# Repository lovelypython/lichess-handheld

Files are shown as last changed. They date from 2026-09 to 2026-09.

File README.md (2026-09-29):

# Lichess Handheld

ESP32-C5 handheld chess terminal project, recovered as a chronological Git history from the Mac/Python simulator through touchscreen testing and the final firmware refinements.

## Development stages

- Python/Mac simulator: board interaction, online flow, clocks, optimistic moves, history navigation, hints, and animation.
- ESP32-C5 PlatformIO port: display, backlight, sleep/wake, Wi-Fi, Lichess client, chess rules, puzzle and online-game screens.
- Touch testing: XPT2046 baseline, standalone diagnostic, independent software SPI, and heartbeat diagnostics.
- Firmware refinement: regional display refresh, TLS setup, landscape rendering, calibrated touch, mirrored-X correction, stale-cell prevention, and puzzle feedback.

## Hardware

Target hardware is a Waveshare ESP32-C5 board with a 480x320 SPI display and XPT2046 touch controller. The current enclosure design is in [hardware/enclosure](hardware/enclosure/).

The enclosure package includes the v05 OpenSCAD source and printable package, plus the v06 rear-shell update. The handoff document records the fit, screw, battery-door, ESP clip, antenna, and Bambu Lab A1 mini printing constraints.

## Build

Install PlatformIO and build the selected historical revision locally:

```bash
pio run -e esp32c5
```

Keep Wi-Fi and Lichess credentials in a local, untracked configuration. This repository contains no passwords, network names, access tokens, compiled firmware images, checksum bundles, or upload wrappers.

## Safety

Do not commit credentials or distribute precompiled firmware. Review the wiring and battery protection before powering the handheld.

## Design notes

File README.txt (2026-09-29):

# Lichess Handheld

This is a recovered historical source snapshot for the ESP32-C5 Lichess handheld project.

## Build from source

Use PlatformIO to build the selected revision locally. No compiled firmware images are distributed in this repository.

```bash
pio run -e esp32c5
```

## Local configuration

Set Wi-Fi and Lichess credentials only in your local configuration. Do not commit passwords, network names, or tokens.

## History

Each commit preserves one recovered development milestone, from the Python simulator through touchscreen diagnostics and the ESP32-C5 firmware.

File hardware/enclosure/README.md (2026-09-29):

# 3D enclosure

Files in this directory:

- `lichess_handheld_enclosure_v05.scad`: parametric source.
- `lichess_handheld_enclosure_v05.zip`: v05 printable package containing the front shell, rear shell, battery cover, ESP clip, and fit-test model.
- `lichess_handheld_enclosure_v06_back.zip`: v06 rear-shell update with the lowered ESP area.
- `GPT6_ESP32C5_Lichess_Enclosure_Handoff.md`: dimensions, fit notes, hardware assumptions, and print guidance.

The v05 design targets the 4-inch 480x320 display, ESP32-C5 board, 18650 battery compartment, rocker switch, antenna clearance, short M2.5 case screws, and Bambu Lab A1 mini FDM printing. STL files remain packaged so the enclosure can be downloaded as one reproducible artifact.

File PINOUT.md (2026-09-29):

# MSP4021 / ST7796S + XPT2046 wiring — v1.0.7

For the first build, only connect the Waveshare ESP32-C5 board and the 4.0" display module.

| LCD pin | Connect to ESP32-C5 | Notes |
|---|---|---|
| VCC | **5V** | Main module power |
| GND | GND | Common ground |
| CS | GPIO23 | LCD chip select |
| RESET | GPIO0 | LCD reset |
| DC/RS | GPIO24 | LOW command / HIGH data |
| SDI (MOSI) | GPIO8 | LCD hardware-SPI MOSI |
| SCK | GPIO10 | LCD hardware-SPI clock |
| **LED** | **GPIO3** | Backlight control; HIGH=on, LOW=off; no 3V3 splitter needed |
| SDO (MISO) | GPIO9 | LCD hardware-SPI MISO |
| T_CLK | **GPIO5** | Touch software-SPI clock |
| T_CS | GPIO1 | Touch chip select |
| T_DIN | **GPIO7** | Touch software-SPI MOSI |
| T_DO | **GPIO25** | Touch software-SPI MISO |
| T_IRQ | GPIO4 | Touch interrupt, active LOW |

SD-card pins are not connected in v1.0.

## Why LED goes to GPIO3

The MSP4021 schematic includes an onboard S8050 transistor and 1 kΩ drive resistor for the backlight.
The module's `LED` header pin is therefore a **logic/PWM control input**, marked as active HIGH by the
manufacturer. It does not need to occupy the ESP32-C5 board's only 3V3 header pin.

This also gives real screen blanking:
- firmware sends ST7796S `DISPOFF` + `SLPIN`;
- GPIO3 goes LOW and the backlight turns off;
- XPT2046 remains powered;
- a touch IRQ wakes the panel and backlight.

## GPIO choices

- GPIO6 and GPIO15 are occupied on the Waveshare board.
- GPIO13/14 are left untouched for native USB/JTAG.
- GPIO27 drives the onboard RGB LED.
- GPIO28 is BOOT.
- GPIO3 is exposed and is used only for LCD backlight control here.
- The ESP32-C5 has one general-purpose hardware SPI controller, so the LCD uses
  hardware SPI and XPT2046 uses an independent software SPI bus on GPIO5/7/25.

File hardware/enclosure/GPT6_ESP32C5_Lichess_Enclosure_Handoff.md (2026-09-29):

# ESP32-C5 Lichess 掌机外壳设计交接文档

> 交给 GPT-6：请**不要沿用之前的外壳结构**，只把下面内容当作硬件尺寸与用户要求，从零重新思考内部布局、固定方式和可打印结构。

## 1. 项目目标

做一个可 3D 打印的手持 Lichess 国际象棋设备外壳。

正面是一块 4.0 英寸 480×320 触摸屏；内部放 Waveshare ESP32-C5 开发板、18650 电池盒和外置棒状 Wi‑Fi 天线；侧面有一个船型电源开关。

用户使用 Bambu Lab A1 mini 打印，优先考虑普通 FDM 可稳定打印和装配，不追求极限薄。

---

## 2. 已确定硬件

### 显示屏

型号/卖家标识：MSP4020 / 4.0 寸 SPI 触摸显示屏

- 尺寸：4.0 inch
- 类型：TFT
- 分辨率：480 × 320
- 驱动 IC：ST7796S
- 显示接口：4-wire SPI
- 触摸：电阻触摸
- 有效显示区域：83.52 × 55.68 mm
- PCB 外形尺寸：108.04 × 61.74 mm
- 屏幕方向：横屏
- 用户希望正面只保留必要边框，不要把有效显示区遮掉
- 屏幕必须有可靠的机械固定，不能只靠壳体夹住后在内部晃动
- 可以使用屏幕 PCB 自带安装孔固定，但正式 CAD 前请重新核对该具体板子的安装孔位置/孔径

### ESP32

开发板：

**Waveshare ESP32-C5-WIFI6-KIT-N32R8-UM**

已知/此前核对的板尺寸：

- PCB/板卡外形约：61.40 × 25.40 mm
- N32R8：32 MB Flash + 8 MB PSRAM
- UM：预焊排针 + 外置天线版本

要求：

- ESP32 必须可靠固定，不能在内部晃动
- 最好利用板上安装孔；如果官方孔位尺寸不能百分百确认，不要猜，改用可靠的压片/夹具/内部小支架
- USB 接口必须从外壳外部可接近，便于烧录、调试和充电
- 不要让固定结构压到 USB、排针、天线连接器或元件

### 外置棒状天线

此前核对的天线本体尺寸约：

- 长度：109 mm
- 直径/最大宽度：约 10 mm

最新要求：

- **天线整个放在外壳内部**
- 不需要让长天线从外壳伸出去
- 必须有现实可装配的路径，不能设计成“封闭管道里凭空出现”
- 最好打开前/后壳后可以直接放入/取出
- 给天线、SMA/同轴转接部分和线缆留余量
- 尽可能让天线与 18650、电池金属件、ESP 大面积地平面保持距离
- 不要求把天线卡得非常死，可以用开口卡座、软胶/泡棉或其他容易装配的方式

### 18650 电池盒

用户购买的是单节 18650 电池盒。

电芯尺寸：

- 18650：直径约 18 mm
- 高度约 65 mm

电池盒外形：

- 76 × 20 × 21 mm
- 引线长度：约 15 cm
- 标称：单节 3.7 V
- 用户可以自行用胶固定电池盒

外壳要求：

- 只需要预留**足够的净空间**，不要为电池盒做过度复杂的硬卡扣
- 建议电池盒周围每个方向适当留打印/装配余量
- 给电池引线留线槽/走线空间
- 背面做**独立电池盖**
- 电池盖必须用螺丝固定
- 电池盖打开后应能维护/更换电池，不必拆整个设备

### 船型开关

卖家参数：

- 面板尺寸：21 × 15 mm
- 开孔尺寸：12 × 19 mm
- 黑色
- 不带灯
- 额定电流：6A / 10A
- 额定电压：250VAC / 125VAC

机械设计要求：

- 外壳开孔按 12 × 19 mm 为基准，并考虑 A1 mini 的 FDM 公差
- 面板厚度/卡扣允许厚度卖家没有给出，**不要假装知道**
- 开关本体背后的实际深度目前也没有精确数据
- 最好让开关区域参数化，实物到手后只需要修改少量参数

---

## 3. 外壳固定方式要求

这是最重要的部分之一。

### 前盖与后盖

- **必须真的机械连接在一起**
- 用户手头主要是短螺丝
- 不要设计成需要 30–40 mm 超长螺丝贯穿整个机身
- 用户提到有一颗特别长的螺丝，但请**完全忽略它，不要围绕它设计**
- 建议重新思考：
  - 接缝附近的螺丝柱
  - 内部框架
  - 舌榫 + 短螺丝
  - 螺母/热熔铜螺母
  - 侧面螺丝
  - 或其他真正适合短螺丝的结构
- 前后壳都要能反复拆装

### 螺丝孔

用户使用 **Bambu Lab A1 mini**。

要求：

- 不要把孔设计得明显过松
- FDM 打印的小孔通常会偏小，要留合理补偿
- 可以使用：
  - 适当 pilot hole 让短螺丝自攻
  - 热熔铜螺母
  - 捕获螺母
  - 如果确认 A1 mini 精度足够，也可以考虑打印螺纹
- 但请优先考虑**可靠、耐拆装、容易打印**
- 如果使用打印内螺纹，请先证明尺寸和螺距适合 0.4 mm 喷嘴，不要只在 CAD 里看起来存在
- 关键孔最好设计 fit-test 小样

### 屏幕固定

- 屏幕必须有独立的螺丝/支撑固定
- 不能只靠前后壳夹住 PCB
- 不允许 PCB 在余量中左右晃
- 螺丝柱不能和前后壳固定柱、ESP 固定柱互相重叠

### ESP 固定

- ESP 必须有机械定位 + 螺丝固定或压片固定
- 不依赖胶
- 不允许板子晃动
- 若使用压片，压片不能碰元件
- 若使用官方安装孔，正式设计前先核对孔位

---

## 4. 结构与布局要求

请从零布局，不要被旧版约束。

基本关系：

- 正面：4" 屏幕
- 后部内部：ESP32 + 电池盒 + 天线
- 后盖：独立电池盖
- 侧面：船型开关
- 外侧：保留 ESP USB 接口访问

目标：

- 能装得进去
- 能实际装配
- 能拆开维修
- 不要有“必须先把某个零件穿过封闭实体才能装”的死结构
- 尽量避免线材被壳体夹住
- 电池、天线、ESP、屏幕背面之间留实际走线空间
- 不需要极限压薄；宁愿多留 1–3 mm，也不要碰撞
- 外壳握持边缘圆润，不要做成尖锐工业盒

---

## 5. 已知尺寸总表

| 部件 | 已知尺寸 |
|---|---|
| 显示屏 PCB | 108.04 × 61.74 mm |
| 显示有效区 | 83.52 × 55.68 mm |
| 显示分辨率 | 480 × 320 |
| ESP32-C5 板 | 约 61.40 × 25.40 mm |
| 棒状天线 | 约 109 × 10 mm |
| 18650 电芯 | Ø18 × 65 mm |
| 18650 电池盒 | 76 × 20 × 21 mm |
| 电池盒引线 | 约 150 mm |
| 船型开关面板 | 21 × 15 mm |
| 船型开关开孔 | 12 × 19 mm |

---

## 6. 当前仍未知、不要猜死的尺寸

这些尺寸在正式外壳里应该参数化或留余量：

1. 船型开关本体深度
2. 船型开关卡扣可接受的面板厚度
3. ESP32-C5 安装孔的绝对坐标（如果官方机械图不能确认）
4. ESP32-C5 预焊排针后的总高度
5. USB-C 连接器相对于板边的完整 3D 包络
6. 天线 SMA/同轴转接部分的实际总长度和弯曲半径
7. 屏幕 PCB 的实际总厚度、排针/触摸控制器最高元件高度
8. 屏幕安装孔绝对位置（正式 CAD 前重新核对对应板子的机械图）
9. 用户现有短螺丝的具体直径、长度、头型

对于这些未知值，优先：

- 参数化
- 留维护空间
- 设计 fit-test
- 等实物到手后微调

不要用未经确认的数字把结构锁死。

---

## 7. 交付要求

请 GPT-6 最终输出：

1. 从零重新思考后的结构方案
2. 各部件内部布局和装配顺序
3. 前壳、后壳、电池盖
4. 屏幕固定结构
5. ESP 固定结构
6. 内置天线固定结构
7. 船型开关孔
8. USB 开口
9. 前后壳短螺丝连接方案
10. 适用于 Bambu Lab A1 mini 的 STL
11. 参数化 CAD / OpenSCAD 源文件
12. 小型 fit-test STL
13. 明确列出仍然依赖实物测量的参数

重点：**先保证结构真的能装、真的能拧、真的能拆，再考虑外观。**

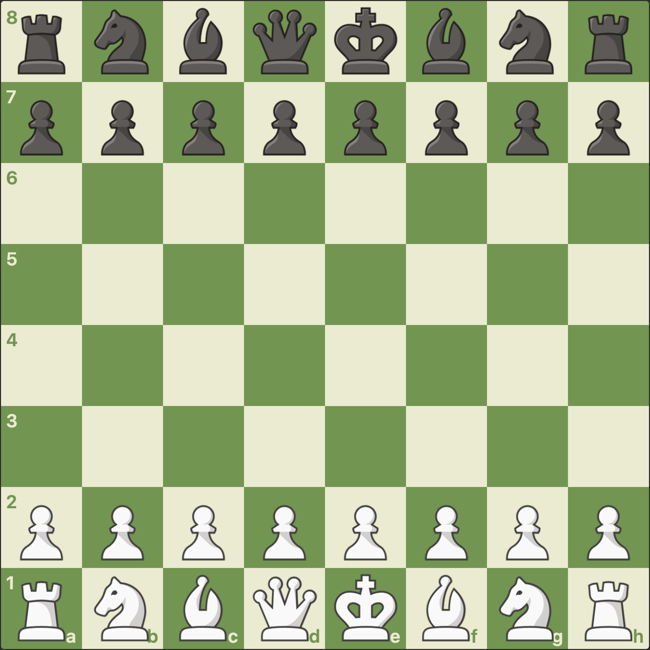
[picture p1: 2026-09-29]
assets_user/source_board.png

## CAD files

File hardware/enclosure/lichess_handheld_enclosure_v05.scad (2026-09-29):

// ESP32-C5 Lichess Handheld enclosure v0.5
// Units: mm
// Main fixes vs v0.4:
// 1) front/back fastening no longer needs 35 mm screws; rear shell now has deep screwdriver wells,
// 2) short M2.5 x 8 screws sit near the seam and thread directly into front-shell pilot bosses,
// 3) other short screws remain local by design: screen->front, ESP clips->back, battery door->back,
// 4) case well outer diameter is enlarged for FDM strength and collision-checked,
// 5) fit-test includes a real short-screw deep-well sample.

$fn = 72;
part = "assembly"; // front, back, battery_cover, esp_clip, fit_test, assembly

// ---------- Main envelope ----------
case_x = 130.0;
case_y = 86.0;
front_z = 7.5;
back_z = 31.5;
wall = 2.4;
corner_r = 6.0;
bezel_t = 2.2;

// ---------- Display: MSP4021 ----------
// Exact from user/seller + official drawing:
// PCB 108.04 x 61.74, AA 83.52 x 55.68,
// mounting pitch 102.04 x 54.90, 4 x Ø3.20,
// total thickness 5.65 without header / 14.00 with header.
screen_pcb_x = 108.04;
screen_pcb_y = 61.74;
screen_clear_total = 0.90; // design clearance, not source dimension
screen_recess_x = screen_pcb_x + screen_clear_total;
screen_recess_y = screen_pcb_y + screen_clear_total;
screen_x0 = (case_x-screen_pcb_x)/2;
screen_y0 = (case_y-screen_pcb_y)/2;

screen_hole_pitch_x = 102.04;
screen_hole_pitch_y = 54.90;
screen_hole_d = 3.20;
screen_hole_x0 = screen_x0 + (screen_pcb_x-screen_hole_pitch_x)/2;
screen_hole_y0 = screen_y0 + (screen_pcb_y-screen_hole_pitch_y)/2;

screen_aa_x = 83.52;
screen_aa_y = 55.68;
screen_aa_left = 14.36;
screen_aa_top = (screen_pcb_y-screen_aa_y)/2;
window_overlap = 0.28; // bezel mask/design choice
screen_window_x = screen_aa_x - 2*window_overlap;
screen_window_y = screen_aa_y - 2*window_overlap;
screen_window_x0 = screen_x0 + screen_aa_left + window_overlap;
screen_window_y0 = screen_y0 + screen_aa_top + window_overlap;

// Screen screws: M3 through PCB Ø3.20, into printed pilot bosses.
screen_boss_d = 7.2;
screen_pilot_d = 2.55;
// Support surface is chosen to leave the PCB inside the front cavity.
// Fine Z adjustment can be made later with thin washers if needed.
screen_support_z = 5.55;
screen_boss_h = screen_support_z - bezel_t;

// ---------- Battery holder ----------
// Exact from user's product image: 76 x 20 x 21 mm.
batt_x = 76.0;
batt_y = 20.0;
batt_z = 21.0;
// Adhesive/service allowance; design clearance.
batt_space_x = 81.0;
batt_space_y = 25.0;
batt_space_z = 23.5;
batt_x0 = (case_x-batt_x)/2;
batt_y0 = 5.5;

// Rear hatch exposes the cell/holder area but leaves end support zones.
batt_hatch_x = 72.0;
batt_hatch_y = 22.0;
batt_hatch_x0 = (case_x-batt_hatch_x)/2;
batt_hatch_y0 = batt_y0 + batt_y/2 - batt_hatch_y/2;
batt_cover_margin = 4.0;
batt_cover_x = batt_hatch_x + 2*batt_cover_margin;
batt_cover_y = batt_hatch_y + 2*batt_cover_margin;
batt_cover_t = 2.2;
batt_cover_lip_h = 0.8;
batt_cover_lip_clear = 0.35;
batt_cover_x0 = batt_hatch_x0 - batt_cover_margin;
batt_cover_y0 = batt_hatch_y0 - batt_cover_margin;

// Four M2.5 battery-door screws.
batt_screw_clear_d = 2.8;
batt_screw_pilot_d = 2.10;
batt_screw_head_d = 5.6;
batt_boss_d = 6.2;
batt_boss_depth = 7.5;
batt_screw_pts = [
    [batt_cover_x0+4.3, batt_cover_y0+4.3],
    [batt_cover_x0+batt_cover_x-4.3, batt_cover_y0+4.3],
    [batt_cover_x0+4.3, batt_cover_y0+batt_cover_y-4.3],
    [batt_cover_x0+batt_cover_x-4.3, batt_cover_y0+batt_cover_y-4.3]
];

// ---------- ESP32-C5-WIFI6-KIT-N32R8-UM ----------
// Exact overall outline from Waveshare drawing: 61.40 x 25.40 mm.
// Waveshare also shows Ø2.00 mounting holes and 50.16 mm X pitch / 22.86 mm Y pitch,
// but the public image does not fully dimension the absolute hole offsets from the overall
// USB-overhang envelope. So this revision intentionally uses screw-down corner clips rather
// than inventing direct-hole coordinates.
esp_x = 61.40;
esp_y = 25.40;
esp_x0 = 8.0;
esp_y0 = 38.5;
esp_pad = 3.8;
esp_under_clear = 6.0; // design space for solder/header protrusion
esp_board_z = back_z - wall - esp_under_clear;

// Four M2.5 screw-down clips around board corners.
esp_clip_boss_d = 6.0;
esp_clip_pilot_d = 2.10;
esp_clip_gap = 2.7;
esp_clip_pts = [
    [esp_x0-esp_clip_gap, esp_y0-esp_clip_gap],
    [esp_x0+esp_x+esp_clip_gap, esp_y0-esp_clip_gap],
    [esp_x0-esp_clip_gap, esp_y0+esp_y+esp_clip_gap],
    [esp_x0+esp_x+esp_clip_gap, esp_y0+esp_y+esp_clip_gap]
];

// Oversized dual-USB service opening; exact connector Z stack is not published,
// so this is intentionally generous rather than pretending to know it exactly.
usb_open_y = 30.0;
usb_open_z = 16.0;
usb_center_y = esp_y0 + esp_y/2;
usb_center_z = esp_board_z - 2.0;

// ---------- Rocker switch ----------
// Exact from user's table: face 21 x 15, panel cutout 12 x 19 mm.
switch_cut_y = 19.35; // +0.35 total FDM clearance
switch_cut_z = 12.35;
switch_center_y = 18.0;
switch_center_z = 17.0;
// Panel thickness is NOT in the seller table. 1.5 mm is a design assumption
// for common snap tabs and is included in the fit-test coupon.
switch_local_wall = 1.5;

// ---------- Internal antenna ----------
// Exact antenna body from Waveshare: 109 x 10 mm, SMA male.
// No wall hole. The whip is pressed into open saddles from the open rear shell
// before the front is screwed on. Ends are open, so the unknown SMA/pigtail
// coupling length does not need to be dimensioned into the case.
ant_len = 109.0;
ant_d = 10.0;
ant_cavity_d = 10.9; // design clearance
ant_x0 = (case_x-ant_len)/2;
ant_y = 70.5;
ant_center_z = back_z - wall - 3.0;
ant_saddle_len = 7.0;
ant_saddle_y = 13.0;
ant_saddle_z = 6.0;
ant_saddle_xs = [22, 47, 92, 117];

// ---------- Front/back case screws ----------
// Six SHORT M2.5 screws. The screw heads do NOT stay on the outer rear surface.
// A deep access well lets a screwdriver reach almost to the front/back seam,
// so an M2.5 x 8 screw only crosses a 3.0 mm bridge and then threads ~5 mm
// into the front-shell pilot boss. No 35 mm case screw is required.
case_screw_clear_d = 2.8;
case_pilot_d = 2.10;
case_head_access_d = 6.2;   // fits common M2.5 pan/socket heads + tool clearance
case_front_boss_d = 6.4;
case_well_od = 9.6;         // back-shell access-well outer diameter
case_screw_bridge_h = 3.0;  // material between deep well seat and front/back seam
case_screw_recommended_len = 8.0;
case_screw_pts = [
    [5.8,5.8], [case_x-5.8,5.8],
    [5.8,case_y-5.8], [case_x-5.8,case_y-5.8],
    [5.8,24.5], [case_x-5.8,32.0]
];

// ---------- Helpers ----------
module rounded_rect_2d(w,h,r) {
    hull() {
        translate([r,r]) circle(r=r);
        translate([w-r,r]) circle(r=r);
        translate([r,h-r]) circle(r=r);
        translate([w-r,h-r]) circle(r=r);
    }
}

module rounded_box(w,h,z,r) {
    linear_extrude(height=z) rounded_rect_2d(w,h,r);
}

module cyl_x(len,d) {
    rotate([0,90,0]) cylinder(h=len,d=d);
}

// ---------- Geometry sanity checks ----------
function dist2d(a,b) = sqrt(pow(a[0]-b[0],2)+pow(a[1]-b[1],2));
function boss_clearance(a,da,b,db) = dist2d(a,b) - da/2 - db/2;

// These asserts are evaluated when the model is compiled. They prevent a future
// parameter edit from silently recreating overlapping screw towers/holes.
for (cp=case_screw_pts)
    for (ep=esp_clip_pts)
        assert(boss_clearance(cp,case_well_od,ep,esp_clip_boss_d) >= 1.0,
               str("Case/ESP boss clearance too small: ",
                   boss_clearance(cp,case_well_od,ep,esp_clip_boss_d), " mm"));
for (sp=[
        [screen_hole_x0,screen_hole_y0],
        [screen_hole_x0+screen_hole_pitch_x,screen_hole_y0],
        [screen_hole_x0,screen_hole_y0+screen_hole_pitch_y],
        [screen_hole_x0+screen_hole_pitch_x,screen_hole_y0+screen_hole_pitch_y]])
    for (ep=esp_clip_pts)
        assert(boss_clearance(sp,screen_boss_d,ep,esp_clip_boss_d) >= 1.0,
               str("Screen/ESP boss clearance too small: ",
                   boss_clearance(sp,screen_boss_d,ep,esp_clip_boss_d), " mm"));

// ---------- Front shell ----------
module screen_bosses() {
    for (dx=[0,screen_hole_pitch_x])
        for (dy=[0,screen_hole_pitch_y])
            translate([screen_hole_x0+dx,screen_hole_y0+dy,bezel_t])
                difference() {
                    cylinder(h=screen_boss_h,d=screen_boss_d);
                    translate([0,0,-0.1]) cylinder(h=screen_boss_h+0.2,d=screen_pilot_d);
                }
}

module case_bosses_front() {
    for (p=case_screw_pts)
        translate([p[0],p[1],bezel_t])
            difference() {
                cylinder(h=front_z-bezel_t,d=case_front_boss_d);
                translate([0,0,-0.1]) cylinder(h=front_z-bezel_t+0.2,d=case_pilot_d);
            }
}

module front_shell() {
    union() {
        difference() {
            rounded_box(case_x,case_y,front_z,corner_r);

            // LCD active-area window.
            translate([screen_window_x0,screen_window_y0,-0.2])
                cube([screen_window_x,screen_window_y,bezel_t+0.4]);
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

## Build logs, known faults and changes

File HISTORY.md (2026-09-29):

# Recovered development history

This repository was reconstructed from the original source exports, in their
chronological order. The Git log is the authoritative timeline.

Stages preserved:

1. Mac Python simulator: initial build through v5.5.
2. ESP32-C5 PlatformIO port: v0.1, v0.2, v0.3, and v1.0.
3. Firmware v1.0.2 through v1.0.7.
4. Independent XPT2046 touch diagnostics (baseline, standalone, software-SPI).
5. Firmware v1.0.8 through v1.0.13: regional refresh, verified TLS, landscape,
   touch calibration, board refresh, and puzzle feedback.

`v1.0.1` is a metadata-only checkpoint because its original source export is
not available. Every other listed checkpoint comes from a recovered source ZIP.

## Credentials

No access token is tracked. Firmware snapshots use
`REPLACE_WITH_YOUR_LICHESS_TOKEN` as a placeholder; provide a fresh token only
in a local, ignored secrets file before building.

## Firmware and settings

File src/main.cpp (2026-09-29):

#include <Arduino.h>
#include <SPI.h>
#include <WiFi.h>
#include <ArduinoJson.h>
#include "config.h"
#include "display.h"
#include "touch.h"
#include "wifi_manager.h"
#include "chess_engine.h"
#include "lichess_client.h"
#include "pieces_user.h"

SPIClass displaySPI(FSPI);
ST7796Display tft(displaySPI);
XPT2046Touch touch;
WiFiManagerLite wifiMgr;
LichessClient api;
QueueHandle_t netQueue=nullptr;

static const uint16_t C_BG=ST7796Display::rgb565(25,27,31);
static const uint16_t C_PANEL=ST7796Display::rgb565(37,39,44);
static const uint16_t C_BTN=ST7796Display::rgb565(65,69,78);
static const uint16_t C_ON=ST7796Display::rgb565(104,135,78);
static const uint16_t C_TEXT=ST7796Display::rgb565(245,245,245);
static const uint16_t C_MUTED=ST7796Display::rgb565(184,184,184);
static const uint16_t C_LIGHT=ST7796Display::rgb565(238,238,210);
static const uint16_t C_DARK=ST7796Display::rgb565(118,150,86);
static const uint16_t C_LAST=ST7796Display::rgb565(205,210,106);
static const uint16_t C_SEL=ST7796Display::rgb565(255,224,48);
static const uint16_t C_SEL_BORDER=ST7796Display::rgb565(255,112,0);
static const uint16_t C_LEGAL=ST7796Display::rgb565(0,210,255);
static const uint16_t C_CAPTURE=ST7796Display::rgb565(255,64,64);
static const uint16_t C_MARK_EDGE=ST7796Display::rgb565(20,24,28);
static const uint16_t C_HINT=ST7796Display::rgb565(255,145,0);
static const uint16_t C_GOOD=ST7796Display::rgb565(102,187,106);
static const uint16_t C_BAD=ST7796Display::rgb565(239,83,80);

struct Rect{int x,y,w,h;};
static bool hit(const Rect&r,int x,int y){return x>=r.x&&x<r.x+r.w&&y>=r.y&&y<r.y+r.h;}
static String clip(const String&s,int n){return s.length()<=size_t(n)?s:s.substring(0,max(0,n-3))+"...";}

enum class Screen{HOME,ONLINE,AI,PUZZLE,ONLINE_CONFIRM,ONLINE_WAIT,GAME,PUZZLE_GAME,PUZZLE_ANSWER,NETWORKS,WIFI_PASSWORD};
Screen screen=Screen::HOME;
bool screenAsleep=false,apiStarted=false,loggedIn=false;
uint32_t lastActivityMs=0,lastTouchMs=0;
String statusText="Starting...",accountId,accountName;

int aiLevel=3,aiTimeIndex=1,onlineTimeIndex=0,puzzleDiffIndex=2;
bool onlineRated=false;
const int AI_TIMES[4][2]={{3,0},{5,3},{10,0},{15,10}};
const int ONLINE_TIMES[4][2]={{10,0},{10,5},{15,10},{30,0}};
const char* PUZZLE_DIFFS[5]={"easiest","easier","normal","harder","hardest"};

int networkPage=0,selectedNetwork=-1;String selectedSSID,wifiPassword;int keyboardMode=0;bool wifiError=false;
static const char* KEY_LOWER[]={"1234567890","qwertyuiop","asdfghjkl.","zxcvbnm_-@"};
static const char* KEY_UPPER[]={"1234567890","QWERTYUIOP","ASDFGHJKL.","ZXCVBNM_-@"};
static const char* KEY_SYMBOL[]={"!\"#$%&'()*","+,-./:;<=>","?@[\\]^_`{|"," }~1234567"};

ChessBoard board;
int selectedSq=-1;
ChessMove lastMove;
bool viewWhite=true;

struct Animation{
  bool active=false;
  char piece=0;
  int from=-1,to=-1;
  int prevX=0,prevY=0;
  uint32_t start=0,lastFrame=0;
};
Animation anim;
static constexpr uint32_t ANIM_MS=100;

String gameId,opponent="-",gameStatus="idle",pendingUci;
bool myWhite=true;
int serverMoveCount=0;
int64_t wtime=-1,btime=-1;int winc=0,binc=0;uint32_t clockSyncMs=0;
uint32_t movePostMs=0,moveStreamMs=0,pendingSentMs=0;
ChessBoard pendingBoard;ChessMove pendingLast;
int64_t pendingWtime=-1,pendingBtime=-1;uint32_t pendingClockSync=0;

String puzzleId,puzzleThemes,puzzleWrongMove;
int puzzleRating=0,puzzleSolutionCount=0,puzzleIndex=0,puzzlePlayedCount=0,puzzleHistoryPly=0;
String puzzleSolution[32],puzzlePlayed[64],puzzleAnswer[32];
ChessBoard puzzleStart;
bool puzzleWhite=true,puzzleLoading=false,puzzleReview=false,puzzleMistake=false,puzzleAnswerShown=false;
int puzzleHintLevel=0,puzzleHintFrom=-1,puzzleHintTo=-1;
bool puzzleReplyPending=false;uint32_t puzzleReplyDue=0;

static void redraw();

static void centerText(const Rect&r,const String&s,uint16_t fg,uint16_t bg,int scale=1){
  int tw=int(s.length())*6*scale,th=7*scale;tft.drawText(r.x+max(0,(r.w-tw)/2),r.y+max(0,(r.h-th)/2),s,fg,bg,scale);
}
static void button(const Rect&r,const String&s,bool on=false,bool enabled=true,int scale=1){
  uint16_t bg=!enabled?ST7796Display::rgb565(48,50,54):(on?C_ON:C_BTN);
  tft.fillRect(r.x,r.y,r.w,r.h,bg);tft.drawRect(r.x,r.y,r.w,r.h,C_PANEL);centerText(r,s,enabled?C_TEXT:C_MUTED,bg,scale);
}
static void header(const String&title){tft.fillScreen(C_BG);tft.drawText(18,15,title,C_TEXT,C_BG,2);button({390,12,72,30},"Home");}

static void ensureApi(){
  if(!apiStarted){netQueue=xQueueCreate(10,sizeof(NetEvent*));api.begin(netQueue);apiStarted=true;}
  if(WiFi.status()==WL_CONNECTED)api.login();
}

static int dispToSq(int dx,int dy){return viewWhite?dx+(7-dy)*8:(7-dx)+dy*8;}
static void sqToDisp(int sq,int&dx,int&dy){int f=sq&7,r=sq>>3;if(viewWhite){dx=f;dy=7-r;}else{dx=7-f;dy=r;}}

static void drawPiecePixel(int px,int py,char p){
  if(!p)return;
#if USER_PIECES_AVAILABLE
  tft.drawRGB565Masked(px,py,pixelsFor(p),maskFor(p),USER_PIECE_W,USER_PIECE_H);
#else
  uint16_t c=ChessBoard::isWhite(p)?C_TEXT:ST7796Display::rgb565(25,25,25);
  tft.fillCircle(px+18,py+18,12,c);tft.drawText(px+15,py+14,String(ChessBoard::typeOf(p)),C_BAD,c,1);
#endif
}

// -------- Board regional refresh -------------------------------------------------
// Cache the visual state of each square. drawBoard() still computes the whole logical
// board, but the ST7796 only receives pixels for squares whose appearance changed.
// This removes the 320x320 full-board flash from selection, legal-move highlights,
// incoming moves and the 100 ms piece animation.
struct SquareVisual {
  char piece=0;
  uint16_t bg=0;
  uint8_t flags=0; // 1 legal, 2 capture, 4 selected border, 8 hint border
};
static SquareVisual boardVisual[64];
static bool boardVisualValid[64]={false};
static int renderedHintLevel=0,renderedHintFrom=-1,renderedHintTo=-1;
static bool boardSceneIdentityValid=false,renderedBoardViewWhite=true;
static String renderedBoardContext;

static void invalidateBoardAll(){
  for(int i=0;i<64;i++)boardVisualValid[i]=false;
  renderedHintLevel=0;renderedHintFrom=renderedHintTo=-1;
  boardSceneIdentityValid=false;
}
// A scene boundary means cached pixels from the previous logical board are not
// reusable. Cancel any overlay animation and force all 64 squares to repaint.
// Local moves/highlights never call this; they continue to use square dirties.
static void beginBoardScene(const char* reason){
  anim.active=false;
  invalidateBoardAll();
  Serial.printf("[LCD] full board refresh: %s\n",reason);
}
static void invalidateBoardSq(int sq){if(sq>=0&&sq<64)boardVisualValid[sq]=false;}
static void invalidateDisplayRectOnBoard(int x,int y,int w,int h){
  int x0=max(0,x),y0=max(0,y),x1=min(319,x+w-1),y1=min(319,y+h-1);
  if(x0>x1||y0>y1)return;
  for(int dy=y0/40;dy<=y1/40;dy++)for(int dx=x0/40;dx<=x1/40;dx++)invalidateBoardSq(dispToSq(dx,dy));
}
static void invalidateHintPath(int from,int to){
  if(from<0||to<0)return;
  int fx,fy,tx,ty;sqToDisp(from,fx,fy);sqToDisp(to,tx,ty);
  int minx=min(fx,tx),maxx=max(fx,tx),miny=min(fy,ty),maxy=max(fy,ty);
  for(int dy=miny;dy<=maxy;dy++)for(int dx=minx;dx<=maxx;dx++)invalidateBoardSq(dispToSq(dx,dy));
}
static bool sameVisual(const SquareVisual&a,const SquareVisual&b){
  return a.piece==b.piece&&a.bg==b.bg&&a.flags==b.flags;
}
static void drawBoardSquare(int sq,const SquareVisual&v){
  int dx,dy;sqToDisp(sq,dx,dy);int x=dx*40,y=dy*40;
  tft.fillRect(x,y,40,40,v.bg);
  drawPiecePixel(x+2,y+2,v.piece);
  if(v.flags&1){
    if(v.flags&2){
      tft.drawRect(x+1,y+1,38,38,C_CAPTURE);tft.drawRect(x+2,y+2,36,36,C_CAPTURE);tft.drawRect(x+3,y+3,34,34,C_CAPTURE);
    }else{
      tft.fillCircle(x+20,y+20,8,C_MARK_EDGE);tft.fillCircle(x+20,y+20,6,C_LEGAL);
    }
  }
  if(v.flags&4){
    tft.drawRect(x+1,y+1,38,38,C_SEL_BORDER);tft.drawRect(x+2,y+2,36,36,C_SEL_BORDER);tft.drawRect(x+3,y+3,34,34,C_SEL_BORDER);
  }
  if(v.flags&8){
    tft.drawRect(x+1,y+1,38,38,C_HINT);tft.drawRect(x+2,y+2,36,36,C_HINT);tft.drawRect(x+3,y+3,34,34,C_HINT);
  }
}
static void drawHintArrow(){
  if(puzzleHintLevel<2||puzzleHintFrom<0||puzzleHintTo<0)return;
  int x0,y0,x1,y1;sqToDisp(puzzleHintFrom,x0,y0);sqToDisp(puzzleHintTo,x1,y1);
  x0=x0*40+20;y0=y0*40+20;x1=x1*40+20;y1=y1*40+20;
  tft.drawLine(x0-1,y0,x1-1,y1,C_HINT);tft.drawLine(x0,y0,x1,y1,C_HINT);tft.drawLine(x0+1,y0,x1+1,y1,C_HINT);tft.fillCircle(x1,y1,7,C_HINT);
}

static void drawBoard(){
  String context=screen==Screen::GAME?String("game:")+gameId:String("puzzle:")+puzzleId;
  if(!boardSceneIdentityValid||renderedBoardContext!=context||renderedBoardViewWhite!=viewWhite){
    for(int i=0;i<64;i++)boardVisualValid[i]=false;
    renderedHintLevel=0;renderedHintFrom=renderedHintTo=-1;
    renderedBoardContext=context;renderedBoardViewWhite=viewWhite;boardSceneIdentityValid=true;
    Serial.printf("[LCD] board cache identity: %s orientation=%s\n",context.c_str(),viewWhite?"white":"black");
  }
  bool legalDest[64]={false},legalCapture[64]={false};
  if(selectedSq>=0){
    ChessMove moves[256];int count=board.generateLegal(moves,256);
    for(int i=0;i<count;i++)if(moves[i].from==selectedSq){
      int to=moves[i].to;legalDest[to]=true;
      legalCapture[to]=legalCapture[to]||bool(moves[i].flags&MF_CAPTURE)||board.pieceAt(to)!=0;
    }
  }

  // The hint arrow is an overlay crossing square boundaries. Dirty the old/new
  // bounding square set when the arrow changes, so it is erased/repainted cleanly.
  if(renderedHintLevel!=puzzleHintLevel||renderedHintFrom!=puzzleHintFrom||renderedHintTo!=puzzleHintTo){
    if(renderedHintLevel>=2)invalidateHintPath(renderedHintFrom,renderedHintTo);
    if(puzzleHintLevel>=2)invalidateHintPath(puzzleHintFrom,puzzleHintTo);
  }

  bool anyChanged=false;
  for(int sq=0;sq<64;sq++){
    int dx,dy;sqToDisp(sq,dx,dy);
    SquareVisual v;
    v.bg=((dx+dy)&1)?C_DARK:C_LIGHT;
    if(lastMove.valid()&&(sq==lastMove.from||sq==lastMove.to))v.bg=C_LAST;
    if(sq==selectedSq)v.bg=C_SEL;
    v.piece=(anim.active&&sq==anim.to)?0:board.pieceAt(sq);
    if(legalDest[sq])v.flags|=1;
    if(legalCapture[sq])v.flags|=2;
    if(sq==selectedSq)v.flags|=4;
    if(puzzleHintLevel&&sq==puzzleHintFrom)v.flags|=8;
    if(!boardVisualValid[sq]||!sameVisual(boardVisual[sq],v)){
      drawBoardSquare(sq,v);boardVisual[sq]=v;boardVisualValid[sq]=true;anyChanged=true;
    }
  }
  if(anyChanged&&puzzleHintLevel>=2)drawHintArrow();
  renderedHintLevel=puzzleHintLevel;renderedHintFrom=puzzleHintFrom;renderedHintTo=puzzleHintTo;
}

static void startAnimation(const ChessBoard&before,const ChessMove&m){
  int fx,fy;sqToDisp(m.from,fx,fy);
  anim.active=true;anim.from=m.from;anim.to=m.to;anim.piece=before.pieceAt(m.from);
  anim.start=millis();anim.lastFrame=0;anim.prevX=fx*40+2;anim.prevY=fy*40+2;
  invalidateBoardSq(m.from);invalidateBoardSq(m.to);drawBoard();
  drawPiecePixel(anim.prevX,anim.prevY,anim.piece);
}
static void updateAnimation(){
  if(!anim.active)return;
  uint32_t now=millis(),e=now-anim.start;
  if(e<ANIM_MS&&anim.lastFrame&&now-anim.lastFrame<12)return; // ~80 fps cap; usually SPI-limited below this
  invalidateDisplayRectOnBoard(anim.prevX,anim.prevY,PIECE_W,PIECE_H);
  if(e>=ANIM_MS){anim.active=false;drawBoard();return;}
  anim.lastFrame=now;
  float t=float(e)/ANIM_MS;t=t*t*(3-2*t);int fx,fy,tx,ty;sqToDisp(anim.from,fx,fy);sqToDisp(anim.to,tx,ty);
  int px=int((fx+(tx-fx)*t)*40)+2,py=int((fy+(ty-fy)*t)*40)+2;
  drawBoard();drawPiecePixel(px,py,anim.piece);anim.prevX=px;anim.prevY=py;
}

static String fmtClock(int64_t base,bool white){
  if(base<0)return "--:--";int64_t ms=base;
  if(board.whiteToMove()==white)ms=max<int64_t>(0,ms-int64_t(millis()-clockSyncMs));
  int sec=ms/1000;char b[16];if(ms<20000)snprintf(b,sizeof(b),"%02d:%02d.%d",sec/60,sec%60,int((ms%1000)/100));
  else snprintf(b,sizeof(b),"%02d:%02d",sec/60,sec%60);return String(b);
}

static int renderedHomeConnection=-1;
static String renderedHomeStatus,renderedHomeAccount;
static void drawHomeDynamic(bool force=false){
  int connection=loggedIn?2:(WiFi.status()==WL_CONNECTED?1:0);
  String status=clip(statusText,73);
  String account=clip(String("Account: ")+(accountName.length()?accountName:"offline"),73);
  if(force||connection!=renderedHomeConnection){
    Rect nr{348,14,114,32};tft.fillRect(nr.x,nr.y,nr.w,nr.h,C_PANEL);
    uint16_t nc=connection==2?C_GOOD:(connection==1?C_HINT:C_BAD);tft.fillCircle(360,30,5,nc);
    tft.drawText(370,22,connection==2?"Online":(connection==1?"Wi-Fi":"Offline"),C_TEXT,C_PANEL,1);
    renderedHomeConnection=connection;
  }
  if(force||status!=renderedHomeStatus){tft.fillRect(18,276,444,18,C_BG);tft.drawText(18,280,status,C_MUTED,C_BG,1);renderedHomeStatus=status;}
  if(force||account!=renderedHomeAccount){tft.fillRect(18,296,444,18,C_BG);tft.drawText(18,300,account,C_MUTED,C_BG,1);renderedHomeAccount=account;}
}
static void drawHome(){
  tft.fillScreen(C_BG);tft.drawText(18,16,"Chess Handheld",C_TEXT,C_BG,2);tft.drawText(18,48,"ESP32-C5 - Lichess",C_MUTED,C_BG,1);
  const Rect cards[3]={{18,88,140,110},{170,88,140,110},{322,88,140,110}};const char* a[]={"Online","AI","Puzzle"};const char*b[]={"Random player","Level 1-8","Lichess API"};
  for(int i=0;i<3;i++){tft.fillRect(cards[i].x,cards[i].y,cards[i].w,cards[i].h,C_PANEL);tft.drawText(cards[i].x+12,cards[i].y+18,a[i],C_TEXT,C_PANEL,2);tft.drawText(cards[i].x+12,cards[i].y+49,b[i],C_MUTED,C_PANEL,1);}
  button({322,216,140,34},"Network");drawHomeDynamic(true);
}

static void drawSelector(Screen which){
  header(which==Screen::AI?"AI game":(which==Screen::ONLINE?"Online match":"Puzzle"));
  if(which==Screen::AI){
    tft.drawText(18,58,"AI strength",C_MUTED,C_BG,1);for(int i=1;i<=8;i++)button({18+(i-1)*55,82,48,34},String(i),aiLevel==i);
    tft.drawText(18,138,"Time control",C_MUTED,C_BG,1);for(int i=0;i<4;i++)button({18+i*108,164,96,36},String(AI_TIMES[i][0])+"+"+AI_TIMES[i][1],aiTimeIndex==i);
    button({18,224,444,44},"Start AI game",true,loggedIn);
  }else if(which==Screen::ONLINE){
    tft.drawText(18,58,"Board API random seek",C_MUTED,C_BG,1);for(int i=0;i<4;i++)button({18+i*108,92,96,36},String(ONLINE_TIMES[i][0])+"+"+ONLINE_TIMES[i][1],onlineTimeIndex==i);
    button({18,151,210,38},"Casual",!onlineRated);button({252,151,210,38},"Rated",onlineRated);button({18,218,444,44},"Review & Continue",true,loggedIn);
  }else{
    tft.drawText(18,58,"Difficulty relative to your rating",C_MUTED,C_BG,1);for(int i=0;i<5;i++)button({18+i*89,90,82,36},PUZZLE_DIFFS[i],puzzleDiffIndex==i);
    button({18,160,444,44},"Get next Lichess puzzle",true,WiFi.status()==WL_CONNECTED);tft.drawText(18,225,"Hints, answer and played-history review",C_MUTED,C_BG,1);
  }
  tft.drawText(18,292,clip(statusText,73),C_MUTED,C_BG,1);
}

static void drawOnlineConfirm(){
  tft.fillScreen(C_BG);tft.drawText(18,15,"Confirm online match",C_TEXT,C_BG,2);tft.drawText(18,50,"Check these settings before matchmaking.",C_MUTED,C_BG,1);
  tft.fillRect(18,80,444,144,C_PANEL);tft.drawText(36,98,"Time control",C_MUTED,C_PANEL,1);tft.drawText(36,119,String(ONLINE_TIMES[onlineTimeIndex][0])+"+"+ONLINE_TIMES[onlineTimeIndex][1],C_TEXT,C_PANEL,2);
  tft.drawText(220,98,"Game type",C_MUTED,C_PANEL,1);tft.drawText(220,119,onlineRated?"Rated":"Casual",C_TEXT,C_PANEL,2);tft.drawText(36,166,"Network",C_MUTED,C_PANEL,1);tft.drawText(36,187,loggedIn?"Connected":"Not connected",loggedIn?C_GOOD:C_BAD,C_PANEL,2);
  tft.drawText(220,177,clip(String("Account: ")+accountName,37),C_TEXT,C_PANEL,1);button({18,250,210,44},"Back");button({252,250,210,44},"Confirm & Search",true,loggedIn);
}
static void drawOnlineWait(){tft.fillScreen(C_BG);tft.drawText(18,28,"Finding opponent...",C_TEXT,C_BG,2);tft.drawText(18,74,String(ONLINE_TIMES[onlineTimeIndex][0])+"+"+ONLINE_TIMES[onlineTimeIndex][1]+(onlineRated?" - Rated":" - Casual"),C_TEXT,C_BG,2);tft.drawText(18,112,"Waiting for Lichess Board API",C_MUTED,C_BG,1);tft.drawText(18,150,clip(statusText,73),C_MUTED,C_BG,1);button({18,232,444,46},"Cancel search");}

static String lastTopClock,lastBottomClock,lastGameTopName,lastGameBottomName,lastGameTelemetry,lastGameStatus;
static void drawGameClockRegion(bool top,bool force=false){
  bool colorWhite=top?!myWhite:myWhite;
  int64_t base=colorWhite?wtime:btime;
  String value=fmtClock(base,colorWhite);
  String& cached=top?lastTopClock:lastBottomClock;
  if(!force&&value==cached)return;
  int y=top?62:140;
  tft.fillRect(326,y,150,34,C_PANEL);
  tft.drawText(330,y+6,value,C_TEXT,C_PANEL,2);
  cached=value;
}
static void drawGameClocks(bool force=false){drawGameClockRegion(true,force);drawGameClockRegion(false,force);}
static void drawGameNames(bool force=false){
  String top=myWhite?opponent:accountName,bot=myWhite?accountName:opponent;
  top=clip(top,23);bot=clip(bot,23);
  if(force||top!=lastGameTopName){tft.fillRect(326,44,150,16,C_PANEL);tft.drawText(330,48,top,C_MUTED,C_PANEL,1);lastGameTopName=top;}
  if(force||bot!=lastGameBottomName){tft.fillRect(326,122,150,16,C_PANEL);tft.drawText(330,126,bot,C_MUTED,C_PANEL,1);lastGameBottomName=bot;}
}
static void drawGameTelemetry(bool force=false){
  String value=String("API ")+(movePostMs?String(movePostMs)+"ms":"-")+"|Sync "+(moveStreamMs?String(moveStreamMs)+"ms":"-");
  if(!force&&value==lastGameTelemetry)return;
  tft.fillRect(326,179,150,38,C_PANEL);
  tft.drawText(330,184,String("API ")+(movePostMs?String(movePostMs)+"ms":"-"),C_MUTED,C_PANEL,1);
  tft.drawText(330,199,String("Sync ")+(moveStreamMs?String(moveStreamMs)+"ms":"-"),C_MUTED,C_PANEL,1);
  lastGameTelemetry=value;
}
static void drawGameStatus(bool force=false){
  String value=clip(statusText,24);if(!force&&value==lastGameStatus)return;
  tft.fillRect(326,302,150,18,C_PANEL);tft.drawText(330,308,value,C_MUTED,C_PANEL,1);lastGameStatus=value;
}
static void drawGameSide(bool force=false){
  if(force){
    tft.fillRect(320,0,160,320,C_PANEL);tft.drawText(330,10,"Online game",C_TEXT,C_PANEL,2);
    button({330,226,140,32},"Home");button({330,264,140,32},"Resign");
    lastTopClock="";lastBottomClock="";lastGameTopName="";lastGameBottomName="";lastGameTelemetry="";lastGameStatus="";
  }
  drawGameNames(force);drawGameClocks(force);drawGameTelemetry(force);drawGameStatus(force);
}
static void drawPuzzleSide(){
  tft.fillRect(320,0,160,320,C_PANEL);tft.drawText(330,10,"Puzzle",C_TEXT,C_PANEL,2);tft.drawText(330,45,clip(String("#")+puzzleId,23),C_MUTED,C_PANEL,1);tft.drawText(330,66,String("Rating ")+puzzleRating,C_TEXT,C_PANEL,2);tft.drawText(330,92,puzzleWhite?"White to move":"Black to move",C_TEXT,C_PANEL,1);
  if(puzzleWrongMove.length())tft.drawText(330,112,clip(String("X ")+puzzleWrongMove,23),C_BAD,C_PANEL,1);
  tft.drawText(330,136,clip(puzzleThemes,23),C_MUTED,C_PANEL,1);
  String progress=puzzleReview?String("History ")+puzzleHistoryPly+"/"+puzzlePlayedCount:String("Played ")+puzzlePlayedCount+"/"+puzzleSolutionCount;
  tft.drawText(330,181,progress,C_TEXT,C_PANEL,1);
  if(puzzleReview){button({330,210,66,28},"< Prev",false,puzzleHistoryPly>0);button({404,210,66,28},"Next >",false,puzzleHistoryPly<puzzlePlayedCount);button({330,244,66,28},"Resume");button({404,244,66,28},"Answer");}
  else{button({330,210,66,28},puzzleHintLevel==0?"Hint":(puzzleHintLevel==1?"Hint 2":"Arrow"));button({404,210,66,28},"Answer");button({330,244,66,28},"< Prev",false,puzzlePlayedCount>0);button({404,244,66,28},"Next >",false,false);}
  button({330,278,66,28},"Home");button({404,278,66,28},"Next Puz",false,!puzzleLoading);tft.drawText(330,308,clip(statusText,24),C_MUTED,C_PANEL,1);
}
static void drawGame(bool forceSide=false){drawBoard();if(screen==Screen::GAME)drawGameSide(forceSide);else drawPuzzleSide();}

static void drawPuzzleAnswer(){
  tft.fillScreen(C_BG);tft.drawText(18,14,"Puzzle answer",C_TEXT,C_BG,2);tft.drawText(18,47,clip(String("#")+puzzleId+" - rating "+puzzleRating,72),C_MUTED,C_BG,1);tft.drawText(18,78,"Full solution steps",C_TEXT,C_BG,2);
  for(int i=0;i<puzzleSolutionCount&&i<12;i++){int col=i<6?0:1,row=i<6?i:i-6;tft.drawText(18+col*225,112+row*25,String(i+1)+". "+clip(puzzleAnswer[i],31),C_TEXT,C_BG,1);}
  button({18,276,210,32},"Back to board");button({252,276,210,32},"Next puzzle",true);
}
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
void loop(){
  processNetEvents();
  while(Serial.available()){char c=Serial.read();if(c=='\n'||c=='\r'){if(serialLine.length()){String cmd=serialLine;serialLine="";if(cmd!="screen sleep")wakeScreen();serialCommand(cmd);lastActivityMs=millis();}}else serialLine+=c;}
  static bool touchDown=false;
  static uint32_t lastTouchPollMs=0;
  TouchPoint touchPoint;
  bool touchSampled=false;
  uint32_t now=millis();
  if(now-lastTouchPollMs>=12){touchPoint=touch.read();touchSampled=true;lastTouchPollMs=now;}
  if(screenAsleep){
    if(touchSampled&&touchPoint.pressed&&!touchDown){touchDown=true;wakeScreen();lastTouchMs=now;}
    else if(touchSampled&&!touchPoint.pressed)touchDown=false;
    delay(3);return;
  }
  if(puzzleReplyPending&&millis()>=puzzleReplyDue){String u=puzzleSolution[puzzleIndex];ChessMove m;ChessBoard before=board;if(board.applyUCI(u,&m)){lastMove=m;puzzlePlayed[puzzlePlayedCount++]=u;puzzleIndex++;startAnimation(before,m);statusText=puzzleIndex>=puzzleSolutionCount?"Solved!":"Your move";}else statusText="Puzzle reply mismatch";puzzleReplyPending=false;drawPuzzleSide();}
  updateAnimation();
  if(touchSampled){
    if(touchPoint.pressed){
      if(!touchDown&&now-lastTouchMs>80){
        Serial.printf("[Touch] raw=%u,%u pressure=%u screen=%d,%d page=%d irq=%d\n",touchPoint.rawX,touchPoint.rawY,touchPoint.pressure,touchPoint.x,touchPoint.y,int(screen),digitalRead(PIN_TOUCH_IRQ));
        handleTouch(touchPoint.x,touchPoint.y);lastTouchMs=now;
      }
      touchDown=true;
    }else{
      if(touchDown)lastTouchMs=now;
      touchDown=false;
    }
  }
  if(SCREEN_IDLE_MS&&millis()-lastActivityMs>=SCREEN_IDLE_MS){sleepScreen();return;}
  static uint32_t lastClock=0;if(screen==Screen::GAME&&millis()-lastClock>=100){lastClock=millis();drawGameClocks();}
  delay(3);
}

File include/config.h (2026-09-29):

#pragma once
#include <Arduino.h>

// -------- Hardware: Waveshare ESP32-C5-WIFI6-KIT-N32R8-UM --------
// Avoid GPIO6 and GPIO15: occupied on the Waveshare board.
// Avoid GPIO13/14 so native USB remains untouched.
// Avoid GPIO27 (onboard RGB LED) and GPIO28 (BOOT).

static constexpr int PIN_SPI_SCK   = 10;
static constexpr int PIN_SPI_MOSI  = 8;
static constexpr int PIN_SPI_MISO  = 9;

static constexpr int PIN_TFT_CS    = 23;
static constexpr int PIN_TFT_DC    = 24;
static constexpr int PIN_TFT_RST   = 0;
static constexpr int PIN_TFT_BL    = 3;   // MSP4021 LED = active-HIGH backlight control input

// XPT2046 uses separate, software-driven SPI pins on ESP32-C5.
static constexpr int PIN_TOUCH_SCK  = 5;
static constexpr int PIN_TOUCH_MOSI = 7;   // T_DIN
static constexpr int PIN_TOUCH_MISO = 25;  // T_DO
static constexpr int PIN_TOUCH_CS   = 1;
static constexpr int PIN_TOUCH_IRQ  = 4;

// MSP4021 has an onboard backlight transistor. LED is a logic/PWM control input,
// so it goes to GPIO3 rather than consuming the ESP board's only 3V3 header pin.
// LCD module VCC goes to 5V while the ESP32-C5 is USB-powered.

// 480 x 320 landscape.
static constexpr int SCREEN_W = 480;
static constexpr int SCREEN_H = 320;
static constexpr uint32_t TFT_SPI_HZ = 20000000;
static constexpr uint32_t TOUCH_SPI_HALF_PERIOD_US = 1;

// Normal screen blanking. Touch IRQ remains alive and wakes the display.
static constexpr uint32_t SCREEN_IDLE_MS = 300000;  // 5 min; set 0 to disable

// ST7796S frame memory is natively 320 columns x 480 rows.  The UI is
// 480x320 landscape, so MADCTL must set MV (row/column exchange).  0x48 is a
// portrait mapping and must not be paired with 480x320 address windows.
// 0x28 = MV | BGR: landscape with the connector/orientation used here.
static constexpr uint8_t ST7796_MADCTL = 0x28;

// Piece size on a 40x40 board square.
static constexpr int PIECE_W = 36;
static constexpr int PIECE_H = 36;

// -------- Built-in Wi-Fi --------
// Priority is the array order. The first visible network is tried first.
struct BuiltinWiFi {
  const char* ssid;
  const char* password;
};

static constexpr BuiltinWiFi BUILTIN_WIFI[] = {
  {"REPLACE_WITH_YOUR_WIFI_SSID", "REPLACE_WITH_YOUR_WIFI_PASSWORD"},
  {"REPLACE_WITH_YOUR_WIFI_SSID",        "REPLACE_WITH_YOUR_WIFI_PASSWORD"},
  {"REPLACE_WITH_YOUR_WIFI_SSID",        "REPLACE_WITH_YOUR_WIFI_PASSWORD"},
};
static constexpr size_t BUILTIN_WIFI_COUNT =
    sizeof(BUILTIN_WIFI) / sizeof(BUILTIN_WIFI[0]);

// One additional Wi-Fi can be selected on the touchscreen and is saved in
// NVS. It is tried after these three built-in networks.

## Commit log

2026-09-29 sim: initial Mac Lichess handheld prototype (sanitized history)
2026-09-29 sim: refine board interaction and online flow (sanitized history)
2026-09-29 sim: refine v5.3 Lichess flow (sanitized history)
2026-09-29 sim: refine v5.4 board controls (sanitized history)
2026-09-29 fw: start ESP32-C5 PlatformIO handheld port (sanitized history)
    [partitions_32MB.csv]
2026-09-29 fw: add v0.3 preview UI and Wi-Fi flow (sanitized history)
2026-09-29 fw: v1.0.2 touch redraw and calibration (sanitized history)
2026-09-29 touch-test: establish XPT2046 baseline (sanitized history)
    [partitions_32MB.csv]
2026-09-29 touch-test: use independent software SPI and heartbeat (sanitized history)
2026-09-29 fw: v1.0.8 add regional display refresh (sanitized history)
    [partitions_32MB.csv]
2026-09-29 fw: v1.0.9 fix native landscape rendering (sanitized history)
    [config.h, main.cpp, touch.cpp]
2026-09-29 fw: v1.0.10 add calibrated touch and regional refresh (sanitized history)
2026-09-29 fw: v1.0.11 correct mirrored touch X mapping (sanitized history)
    [main.cpp, touch.cpp]
2026-09-29 fw: v1.0.12 prevent stale board cells during refresh (sanitized history)
    [main.cpp]
2026-09-29 fw: v1.0.13 add puzzle feedback and selection fixes (sanitized history)
    [main.cpp]
2026-09-29 docs: add clean project README and recovered 3D enclosure package
    [lichess_handheld_enclosure_v05.scad]
